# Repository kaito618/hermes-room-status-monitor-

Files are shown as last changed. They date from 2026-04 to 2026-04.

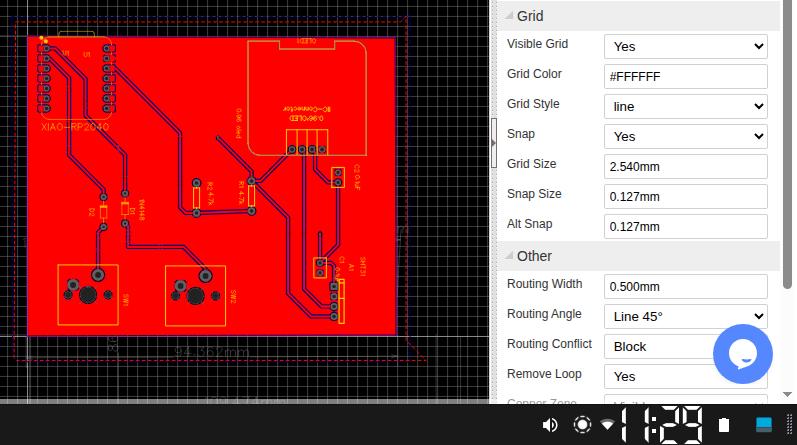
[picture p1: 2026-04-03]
pcb/Screenshot_2026-04-03_23-29-47.jpg

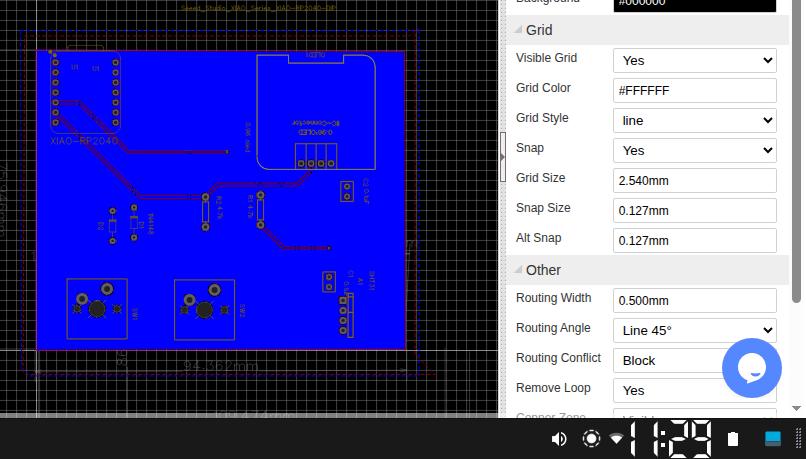
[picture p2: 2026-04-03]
pcb/Screenshot_2026-04-03_23-29-31.jpg

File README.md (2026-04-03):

# hermes-room-status-monitor-
i'm making a device to monitor my room's temp and humidity 

schematic done
i chose what sensor i want to use i'll use the SHT31-DIS-B2.5KS to make a room temp and hum monitor


added 2 buttons to control the device and an oled screen to show room status

schematic
schematic

done w pcb kicad 
im having some real issues with my footprints and my kicad ill be posting the pcb pic later on when i fix everything

MY KICAD DIED guess my 18 yr old laptop didn't wanna take it anymore or maybe it's linux gon no clue anyways after hours of debegguing i switched to easyeda adn redid averything





pcb done easyeda
i finished the pcb layout and wiring and getting my 3d models ready




3d model 



## 🛠 Bill of Materials (BOM)

| Component | Description | Qty | Est. Price (EGP) | Source / Link |
| :--- | :--- | :---: | :--- | :--- |
| **Microcontroller** | Seeed Studio XIAO RP2040 | 1 | 499 | [amazoneg](https://www.amazon.eg/-/en/gp/product/B0GHNR74YH/ref=ewc_pr_img_2?smid=A1FZS2ISSCLNWQ&psc=1) |
| **Sensor** | SHT31 High-Precision Temp & Humidity ($I^2C$) | 1 | 195.00 | [RAM Electronics](https://www.ram-e-shop.com/shop/kit-sht31-sht31-temperature-humidity-sensor-module-9216) |
| **Display** | 0.96" OLED 128x64 ($I^2C$ SSD1306) | 1 | 160.00 | [RAM Electronics](https://www.ram-e-shop.com/shop/oled-0-96-4pin-oled-0-96-4pin-lcd-display-module-i2c-iic-communicate-7772) |
| **Buttons** | mx switches (THT) | 2 | 175 | [amazoneg](https://www.amazon.eg/-/en/gp/product/B0GRPPX2T6/ref=ewc_pr_img_1?smid=A209IF81KPKFRD&psc=1) |
| **Resistors** | 10k Ohm 1/4W (Pull-ups for $I^2C$) | 2 | 4 | [RAM Electronics](https://www.ram-e-shop.com/shop/carbon-resistance-1-4w-price-per-4-resistors-9506#attr=301) |
| **capacitors** | 2.54mm Female Header Strip (1x40) | 2 | 2 | [RAM Electronics](https://www.ram-e-shop.com/shop/c-10u25v-capacitor-10uf-25v-6095) |

| **TOTAL** | **Estimated Project Cost** | | **~1034egp 19.03 usd** | |

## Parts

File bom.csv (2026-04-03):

Component | Description | Qty | Price (EGP) | Source / Link
Microcontroller | Seeed Studio XIAO RP2040 | 1 | 499.00 | https://www.amazon.eg/-/en/gp/product/B0GHNR74YH/
Sensor | SHT31 High-Precision Temp & Humidity (I^2C) | 1 | 195.00 | https://www.ram-e-shop.com/shop/kit-sht31-sht31-temperature-humidity-sensor-module-9216
Display | 0.96" OLED 128x64 (I^2C SSD1306) | 1 | 160.00 | https://www.ram-e-shop.com/shop/oled-0-96-4pin-oled-0-96-4pin-lcd-display-module-i2c-iic-communicate-7772
Buttons | mx switches (THT) | 2 | 175.00 | https://www.amazon.eg/-/en/gp/product/B0GRPPX2T6/
Resistors | 10k Ohm 1/4W (Pull-ups for I^2C) | 2 | 4.00 | https://www.ram-e-shop.com/shop/carbon-resistance-1-4w-price-per-4-resistors-9506#attr=301
capacitors | 2.54mm Female Header Strip (1x40) | 2 | 2.00 | https://www.ram-e-shop.com/shop/c-10u25v-capacitor-10uf-25v-6095
TOTAL | Estimated Project Cost |  | ~1034.00 | 19.03 USD

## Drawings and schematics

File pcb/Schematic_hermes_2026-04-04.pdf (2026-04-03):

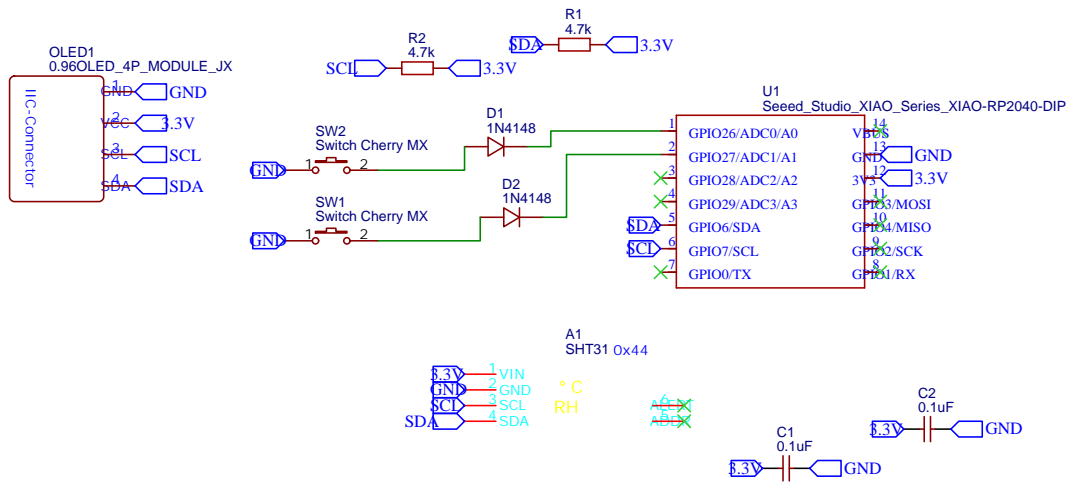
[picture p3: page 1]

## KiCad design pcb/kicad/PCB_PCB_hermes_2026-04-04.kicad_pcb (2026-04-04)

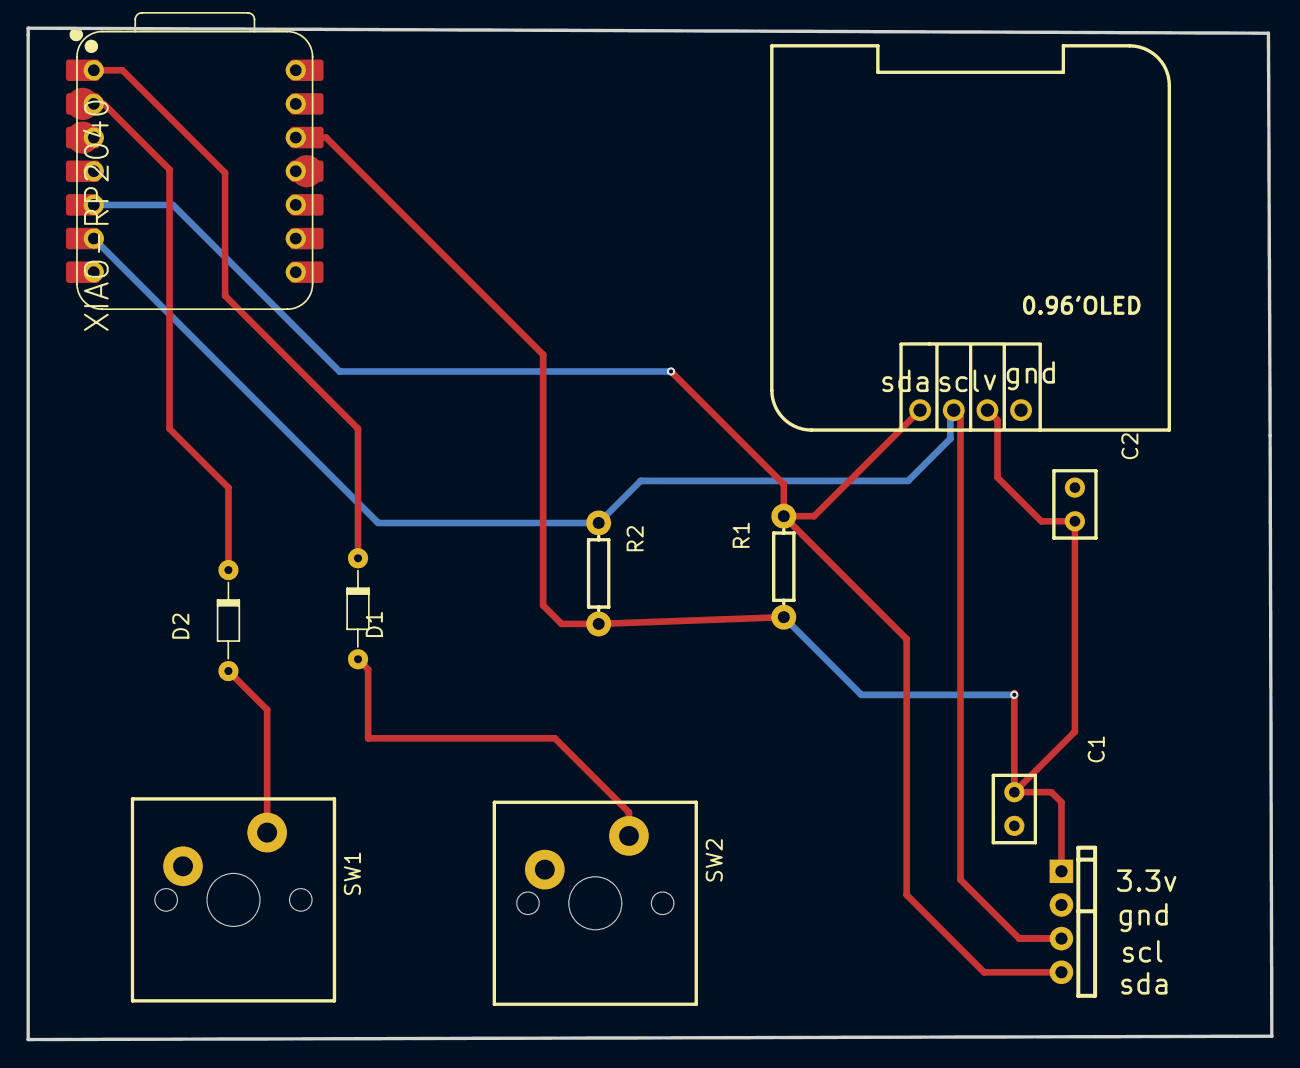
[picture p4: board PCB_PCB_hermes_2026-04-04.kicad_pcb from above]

Board: 2 copper layers, 93.9 x 76.3 mm, 11 parts (0 on the bottom side), 8 nets.

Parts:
A1: SHT31
C1, C2: 0.1uF; CERAMIC CAPACITOR_100NF
D1, D2: 1N4148; 1N418 PAS 7.62MM
OLED1: 0.96'OLED; 0.96OLED_4P
R1, R2: 4.7k; AXIAL-0.3
SW1, SW2: Switch Cherry MX; SWITCH CHERRY MX
U1: XIAO-RP2040; VARISTOR_XIAO-RP2040-DIP

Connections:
3.3V: A1.1, C1.1, C2.1, OLED1.2, R1.2, R2.2, U1.12
GND: A1.2, C1.2, C2.2, OLED1.1, SW1.1, SW2.1, U1.13
SCL: A1.3, OLED1.3, R2.1, U1.6
SDA: A1.4, OLED1.4, R1.1, U1.5
SW1_2: D2.2, SW1.2
SW2_2: D1.2, SW2.2
U1_1: D1.1, U1.1
U1_2: D2.1, U1.2

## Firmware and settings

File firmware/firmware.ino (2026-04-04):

#include <Wire.h>
#include <Adafruit_GFX.h>
#include <Adafruit_SSD1306.h>
#include <Adafruit_SHT31.h>

#define BT_MODE 0 
#define BT_PAGE 1 

Adafruit_SSD1306 oled(128, 64, &Wire, -1);
Adafruit_SHT31 sensor = Adafruit_SHT31();

bool f_unit = false;
bool p_toggle = false;
unsigned long prev_ms = 0;

void setup() {
  pinMode(BT_MODE, INPUT_PULLUP);
  pinMode(BT_PAGE, INPUT_PULLUP);

  if(!oled.begin(SSD1306_SWITCHCAPVCC, 0x3C)) {
    for(;;); 
  }
  
  oled.clearDisplay();
  oled.setTextSize(1);
  oled.setTextColor(1);

  if (!sensor.begin(0x44)) {
    oled.setCursor(0,0);
    oled.print("SHT31 ERROR");
    oled.display();
    while (1);
  }
}

void loop() {
  if (digitalRead(BT_MODE) == LOW) {
    f_unit = !f_unit;
    delay(250); 
  }

  if (digitalRead(BT_PAGE) == LOW) {
    p_toggle = !p_toggle;
    delay(250); 
  }

  if (millis() - prev_ms > 800) {
    float t_raw = sensor.readTemperature();
    float h_raw = sensor.readHumidity();
    prev_ms = millis();

    oled.clearDisplay();
    oled.setCursor(0, 0);
    oled.print(p_toggle ? "SYS_STATUS" : "HERMES_V1");
    oled.drawLine(0, 9, 128, 9, 1);

    if (p_toggle) {
      oled.setCursor(0, 15);
      oled.print("MCU: RP2040");
      oled.setCursor(0, 25);
      oled.print("I2C: 0x44, 0x3C");
      oled.setCursor(0, 35);
      oled.print("UP: "); oled.print(millis()/1000); oled.print("s");
    } else {
      if (!isnan(t_raw)) {
        float val = f_unit ? (t_raw * 1.8 + 32) : t_raw;
        oled.setCursor(0, 18);
        oled.print("TEMP:");
        oled.setTextSize(3); 
        oled.setCursor(0, 30);
        oled.print(val, 1);
        oled.setTextSize(1);
        oled.print(f_unit ? " F" : " C");
        
        oled.setCursor(85, 55);
        oled.print("H: "); oled.print((int)h_raw); oled.print("%");
      }
    }
    oled.display();
  }
}
